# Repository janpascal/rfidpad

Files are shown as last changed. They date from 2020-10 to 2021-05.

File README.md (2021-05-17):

# rfidpad
Hardware, firmware, and Home Assistant integration for an ESP32 based device to enable and disable a Home Assistant alarm system

# Design goals
- low-cost (at most 50 euros per panel, comparable to the Zipato RFID Mini Keypad)
- arm and disarm Home Assistant alarm system using cheap RFID tags
- panel should not require any wiring
- panel should run on battery power for at least one year

And if possible also:
- Configure tags in Home Assistant UI
- Display list of recent arm and disarm actions in Home Assistant
- Associate name with each tag
- Enabled tags should not be stored in the panel, only in Home Assistant

# Hardware panel
- Based on low power ESP32 board from EZSBC with a LiPo battery (https://www.ezsbc.com/index.php/products/wifi01-cell10.html) and PN532 board from Elechouse (https://www.elechouse.com/elechouse/index.php?main_page=product_info&cPath=90_93&products_id=2276).
- The device will spend most of the time in deep sleep. The ESP32 should draw less than 20 μA in deep sleep. The PN532 chip itself has a deep sleep mode that should draw around 10 μA.
- Three pushbuttons to wake up the device and select the new alarm mode (disarm, arm home, arm away)
- After waking up the device, it will connect to WiFi and an MQTT server
- When an RFID tag is detected, its ID is sent over MQTT, together with the desired new alarm mode
- The device listens on MQTT for messages about the Home Assistant alarm mode.
- Three LEDs on the panel to display the current alarm mode. Also serves as feedback to the user that the mode has been successfully changed

## Hardware challenges:
- Power usage. The PN532 board has an LED that burns as long as the board is powered. That means the Vcc of the PN532 will need to be switched using e.g. a FET to prevent the board from using too much power during the deep sleep period. Also, the deep sleep mode of the PN532 chip isn't supported by the library supplied by Elechouse.
- Housing, including the pushbutton and status LEDs.

# Enclosure
The enclosure is designed with FreeCad. It contains of three parts which should be 3D printable.

# Firmware
Use the Arduino IDE to compile the firmware. Select the ESP32 dev board as the
target. Upload it to your RFIDPad

# Home Assistant custom component

## Prerequisities
You will need an MQTT server such as Mosquitto. Configure MQTT in your Home
Assistant installation. Give the homeassistant user read access to
`rfidpad/discovery/#`, to `rfidpad/+/battery` and to `rfidpad/+/action`.
Give it write access to `rfidpad/+/status`.

Add an `rfidpad` user and give it write access to 
`rfidpad/discovery/#`, to `rfidpad/+/battery` and to `rfidpad/+/action`.
Give it write access to `rfidpad/+/status`.

## Installation via HACS
- First install HACS in Home assistant. See https://hacs.xyz/ for instructions.
- Open the Community panel in Home Assistant
- Open the 'hamburger menu' and select 'Custom repositories'
- Enter https://github.com/janpascal/rfidpad where it says 'Add custom repository URL'. In the Category dropdown select 'Integration' and click 'Add' 
- Now press the big '+' on the bottom of the screen. Search for 'RFIDPad', select it and click on 'Install this repository in HACS'
- Configure the RFID custom component by filling in the base MQTT topic. The default (rfidpad) will do if you haven't changed the firmware.

## Configuration
The tags that can be used to arm/disarm your Home Assistant alarm need to be
configured in Home Assistant's `configuration.yaml` configuration file.
Add a snippet like:

```
rfidpad:
  tags:
    - tag: ABCD0145
      name: Mary
    - tag: 45AB12EC
      name: John
```

and restart Home Assistant

## Automations

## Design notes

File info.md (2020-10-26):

# Development version
Please do not install this integration yet. It is in heavy development and probably will ot work at all with  your device.

{% if prerelease %}
### NB!: This is a Beta version!
{% endif %}

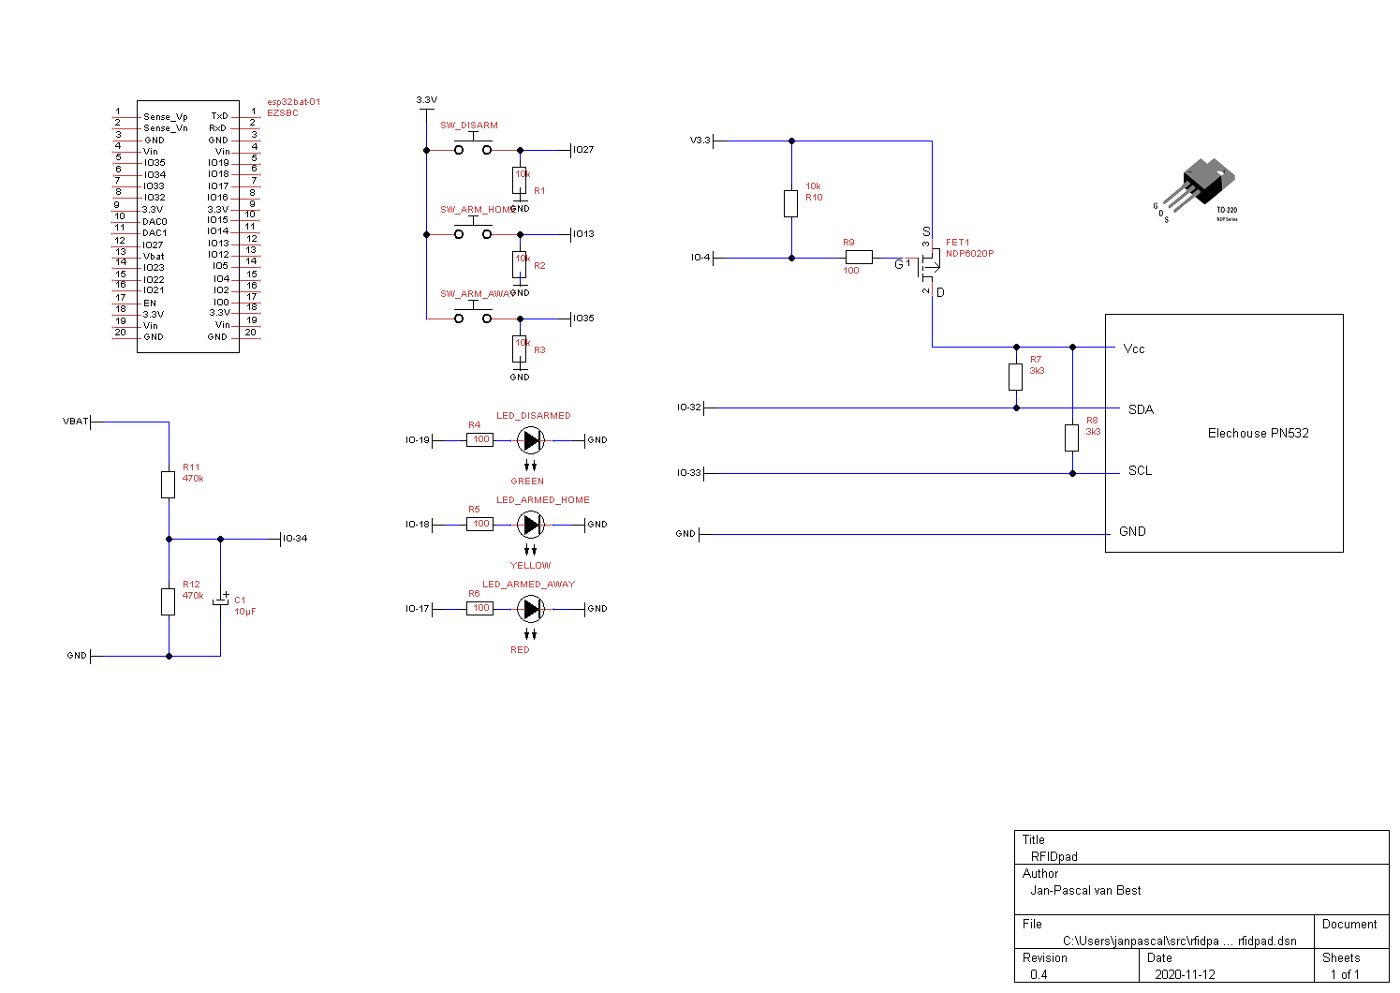
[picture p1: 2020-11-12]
schematic/rfidpad.png

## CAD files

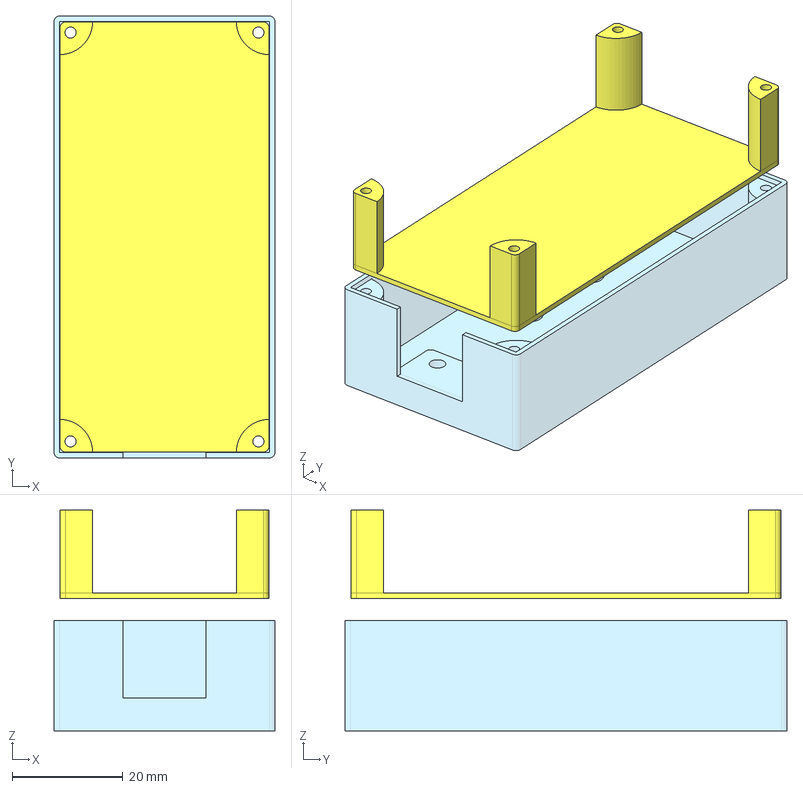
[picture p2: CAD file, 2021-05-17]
enclosure/rfidpad.FCStd
40.0 x 80.0 x 40.0 mm
Inlay

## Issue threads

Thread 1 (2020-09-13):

Panel uses too much power

janpascal, 2020-09-13:
At least, use a FET or something to cut the power to the PN532 board, since if anything the LED keeps burning when the rest of the panel is in deep sleep

janpascal, 2020-11-12:
Should be fixed now by using a FET to cut power to the PN532 board. With lots of help from the Arduino forum: https://forum.arduino.cc/?topic=705265

Closed 2020-11-12.

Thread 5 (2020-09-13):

Housing

janpascal, 2020-09-13:
Design a 3d printable housing for the rfidpad, including the pushbuttons, LEDs, esp32 board, pn532 board, maybe a reset pin, and a usb connector for charging the battery

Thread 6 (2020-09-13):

Battery level monitoring

janpascal, 2020-09-13:
also send out battery low warning, or the battery level itself, over MQTT
Shut down the device if the battery level gets too low to prevent damaging the battery

janpascal, 2020-11-12:
Battery monitor is implemented in schematic, firmware and home assistant integration.

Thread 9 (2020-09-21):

Allow access to config

janpascal, 2020-09-21:
Currently the device enters deep sleep in five seconds after boot. Make it possible to keep it awake long enough to change the device configuration

janpascal, 2020-11-12:
Fixed in firmware. Press multiple buttons at the same time to enter config mode

Closed 2020-11-12.

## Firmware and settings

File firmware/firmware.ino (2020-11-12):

/**
   firmware.ino -- part of rfidpad. 

   rfidpad is an ESP32 based device to enable and disable a Home 
   Assistant alarm system using RFID tags

   See https://github.com/janpascal/rfidpad for a hardware description
   and Home Assistant integration.

   Copyright (C) 2020 Jan-Pascal van Best <janpascal@vanbest.org>

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
    You should have received a copy of the GNU General Public License
    along with this program.  If not, see <https://www.gnu.org/licenses/>.
*/

#include <WiFiClientSecure.h>
#include <PubSubClient.h>
#include <IotWebConf.h>
#include <ArduinoJson.h>
#include <esp_system.h>

#define DEBUG
#include <Wire.h>
#include <PN532_debug.h>
#include <PN532_I2C.h>
#include <PN532.h>


#define DBG_OUTPUT_PORT Serial
#include <SPIFFS.h>

// I2C pins
#define PIN_SDA (32)
#define PIN_SCL (33)

// Pushbutton pins
#define PIN_DISARM_BUTTON 27
#define PIN_ARM_HOME_BUTTON 13
#define PIN_ARM_AWAY_BUTTON 35

// LED pins
#define PIN_DISARMED_LED 19
#define PIN_ARMED_HOME_LED 18
#define PIN_ARMED_AWAY_LED 17

// FET pin
#define PIN_ENABLE_PN532 4

// Battery voltage divider pin
#define PIN_BATTERY_DIVIDER 34


// -- When CONFIG_PIN is pulled to ground on startup, the Thing will use the initial
//      password to buld an AP. (E.g. in case of lost password)
//      -1 means no config pin
#define CONFIG_PIN -1

// -- Status indicator pin.
//      First it will light up (kept LOW), on Wifi connection it will blink,
//      when connected to the Wifi it will turn off (kept HIGH).
#define STATUS_PIN -1

// Stay awake for 10 seconds during normal operations
#define NORMAL_WAKE_TIME 10000

// Stay away for 10 minutes when multiple buttons were pressed during startup
#define CONFIG_WAKE_TIME 600000

// If no buttons are pushed, stay in deep sleep for this many microseconds
// When woken up, only send battery info and re-enter deep sleep
// Wake up every 24 hours
#define DEEP_SLEEP_TIMER_MICROSECONDS (1000000LL * 3600LL * 24)
// For debugging and power usage measurements: Wake up every minute
// #define DEEP_SLEEP_TIMER_MICROSECONDS (1000000LL * 60)

// Internal buffer size for MQTT library. Default of 256 is too small for discovery messages
#define MQTT_BUFFER_SIZE 512

enum requested_state_t {
  requested_state_unknown,
  requested_state_disarm_button,
  requested_state_arm_home_button,
  requested_state_arm_away_button,
  requested_state_config,
  requested_state_report
};

static const char *requested_state_actions[] = { "SCAN", "DISARM", "ARM_HOME", "ARM_AWAY", "SCAN", "SCAN" };

enum state_t {
  state_unknown,
  state_disarmed,
  state_disarmed_pending,
  state_armed_home,
  state_armed_home_pending,
  state_armed_away,
  state_armed_away_pending,
  state_config,                // CA certificate incomplete or double buttons pressed
  state_report                 // Just report battery level over MQTT and sleep again
};

// -- Initial name of the Thing. Used e.g. as SSID of the own Access Point.
const char thingName[] = "keypad";

// -- Initial password to connect to the Thing, when it creates an own Access Point.
const char wifiInitialApPassword[] = "pad323232";

const char action_topic_name[] = "action";
const char state_topic_name[] = "status";
const char battery_level_topic_name[] = "bat";

const char* caFilename = "/ca.crt";

const char* sw_version = "0.1";
const char* manufacturer = "janpascal@vanbest.org";
const char* model = "RFIDPAD v0.4";

// -- Configuration specific key. The value should be modified if config structure was changed.
#define CONFIG_VERSION "rfidpad_v1"

#define STRING_LEN 128
#define PORT_LEN 5
#define MAX_TOPIC_LEN 256

// -- Callback method declarations.
void configSaved();
boolean formValidator();

DNSServer dnsServer;
WiFiClientSecure net;
WebServer server(80);
PubSubClient mqttClient(net);
File fsUploadFile; //holds the current upload

TwoWire wire(0);
PN532_I2C pn532_i2c(wire);
PN532 pn532(pn532_i2c);

char mqttServerValue[STRING_LEN];
char mqttServerPortValue[PORT_LEN];
char mqttUserNameValue[STRING_LEN];
char mqttUserPasswordValue[STRING_LEN];
char mqttTopicPrefixValue[STRING_LEN];

IotWebConf iotWebConf(thingName, &dnsServer, &server, wifiInitialApPassword, CONFIG_VERSION);
IotWebConfParameter mqttServerParam = IotWebConfParameter("MQTT server", "mqttServer", mqttServerValue, STRING_LEN, "text", NULL, "bree.vanbest.eu");
IotWebConfParameter mqttServerPortParam = IotWebConfParameter("MQTT port", "mqttPort", mqttServerPortValue, PORT_LEN, "text", NULL, "1883"); // , "1883 for MQTT, 8883 for MQTTS");
IotWebConfParameter mqttUserNameParam = IotWebConfParameter("MQTT user", "mqttUser", mqttUserNameValue, STRING_LEN, "text", NULL, "keypad");
IotWebConfParameter mqttUserPasswordParam = IotWebConfParameter("MQTT password", "mqttPass", mqttUserPasswordValue, STRING_LEN, "password", NULL, "aeSheeciingeib6G");
IotWebConfParameter mqttTopicPrefixParam = IotWebConfParameter("MQTT prefix", "mqttPrefix", mqttTopicPrefixValue, STRING_LEN, "text", NULL, "rfidpad");
// -- We can add a legend to the separator
//IotWebConfSeparator separator2 = IotWebConfSeparator("Calibration factor");

boolean needMqttConnect = false;
unsigned long lastMqttConnectionAttempt = 0;
static int current_led = 0;
unsigned long mqttLastBatteryMessageTimestamp = 0;

// Overwritten at startup
char mqtt_status_channel[MAX_TOPIC_LEN] = "rfidpad/status";
char mqtt_action_channel[MAX_TOPIC_LEN] = "rfidpad/action";
char mqtt_discovery_channel[MAX_TOPIC_LEN] = "rfidpad/discovery/000000000000";
char mqtt_bat_channel[MAX_TOPIC_LEN] = "rfidpad/bat";
char device_id[] = "000000000000";
char device_name[STRING_LEN] = "<unknown>";

requested_state_t requested_state = requested_state_unknown;
state_t current_state = state_unknown;
int last_state_change = 0;
char mqtt_message_to_send[255] = "";

void setup()
{
  Serial.begin(115200);
  Serial.println();
  Serial.println("Starting up...");

  if (PIN_BATTERY_DIVIDER > 0) pinMode(PIN_BATTERY_DIVIDER, INPUT);

  if (PIN_DISARMED_LED > 0) pinMode(PIN_DISARMED_LED, OUTPUT);
  if (PIN_ARMED_HOME_LED > 0) pinMode(PIN_ARMED_HOME_LED, OUTPUT);
  if (PIN_ARMED_AWAY_LED > 0) pinMode(PIN_ARMED_AWAY_LED, OUTPUT);

  pinMode(PIN_DISARM_BUTTON, INPUT);
  pinMode(PIN_ARM_HOME_BUTTON, INPUT);
  pinMode(PIN_ARM_AWAY_BUTTON, INPUT);

  if (PIN_ENABLE_PN532 > 0) {
    pinMode(PIN_ENABLE_PN532, OUTPUT);
    digitalWrite(PIN_ENABLE_PN532, LOW);
  }

  requested_state = get_requested_state();
  if (requested_state == requested_state_config) {
    current_state = state_config;
  } else if (requested_state == requested_state_report) {
    current_state = state_report;
  } else {
    current_state = state_unknown;
  }


  // if (FORMAT_FILESYSTEM) SPIFFS.format();
  SPIFFS.begin();                           // Start the SPI Flash Files System

  iotWebConf.setStatusPin(STATUS_PIN);
  iotWebConf.setConfigPin(CONFIG_PIN);

  iotWebConf.addParameter(&mqttServerParam);
  iotWebConf.addParameter(&mqttServerPortParam);
  iotWebConf.addParameter(&mqttUserNameParam);
  iotWebConf.addParameter(&mqttUserPasswordParam);
  iotWebConf.addParameter(&mqttTopicPrefixParam);

  iotWebConf.setConfigSavedCallback(&configSaved);
  iotWebConf.setFormValidator(&formValidator);
  iotWebConf.setWifiConnectionCallback(&wifiConnected);
  //iotWebConf.getApTimeoutParameter()->visible = true;
  iotWebConf.skipApStartup(); // Do not always spend first 30 seconds in AP mode, only if config invalid

  // -- Initializing the configuration.
  bool validConfig = iotWebConf.init();
  if (!validConfig)
  {
    Serial.println("Invalid config, resetting Wifi info...");
    iotWebConf.resetWifiAuthInfo();
    strncpy(mqttServerValue, mqttServerParam.defaultValue, STRING_LEN);
    strncpy(mqttServerPortValue, mqttServerPortParam.defaultValue, PORT_LEN);
    strncpy(mqttUserNameValue, mqttUserNameParam.defaultValue, STRING_LEN);
    strncpy(mqttUserPasswordValue, mqttUserPasswordParam.defaultValue, STRING_LEN);
    strncpy(mqttTopicPrefixValue, mqttTopicPrefixParam.defaultValue, STRING_LEN);
  }

  Serial.println("Setting ca certificate to connection to MQTT server");
  if (!SPIFFS.exists(caFilename)) {
    Serial.printf("CA file %s does not exist!\n", caFilename);
  }
  File file = SPIFFS.open(caFilename, "r");

  if(!file) {
    Serial.printf("Error opening the CA file %s\n.", caFilename);
  } else {
    String ca_cert = file.readString();
    Serial.printf("CA Root certificate: %s\n", ca_cert.c_str());
    char *tmp;  
    tmp = (char *)malloc(sizeof(char) * (ca_cert.length()+1));
    strcpy(tmp, ca_cert.c_str());
      
    net.setCACert(tmp);
    file.close();
    // free(tmp);      
  }

  IotWebConfParameter* ap_passwd_param = iotWebConf.getApPasswordParameter();
  char* pw = ap_passwd_param->valueBuffer;
  Serial.print("Config password: ");
  Serial.println(pw);

  IotWebConfParameter* thing_name_param = iotWebConf.getThingNameParameter();
  strncpy(device_name, thing_name_param->valueBuffer, sizeof(device_name));
  device_name[sizeof(device_name)-1] = 0;
  Serial.printf("Device name: %s\n", device_name);

  Serial.printf("Fetching hardware id...\n");
  fetch_device_id();
  Serial.printf("Device ID: %s\n", device_id);
  
  Serial.println("Setting up MQTT topic names...");
  snprintf(mqtt_status_channel, MAX_TOPIC_LEN, "%s/%s/%s", mqttTopicPrefixValue, device_id, state_topic_name);
  snprintf(mqtt_action_channel, MAX_TOPIC_LEN, "%s/%s/%s", mqttTopicPrefixValue, device_id, action_topic_name);
  snprintf(mqtt_discovery_channel, MAX_TOPIC_LEN, "%s/discovery/%s", mqttTopicPrefixValue, device_id);
  snprintf(mqtt_bat_channel,    MAX_TOPIC_LEN, "%s/%s/%s", mqttTopicPrefixValue, device_id, battery_level_topic_name);
  Serial.printf("* status topic: %s\n", mqtt_status_channel);
  Serial.printf("* action topic: %s\n", mqtt_action_channel);
  Serial.printf("* config topic: %s\n", mqtt_discovery_channel);
  Serial.printf("* battery level topic: %s\n", mqtt_bat_channel);

  // -- Set up required URL handlers on the web server.
  server.on("/", handleRoot);
  server.on("/config", [] { iotWebConf.handleConfig(); });
  server.on("/upload_cert", HTTP_POST,                       // if the client posts to the upload page
    [](){ server.send(200); },                          // Send status 200 (OK) to tell the client we are ready to receive
    handleCertUpload                                    // Receive and save the file
  );
  server.onNotFound([]() {
    iotWebConf.handleNotFound();
  });


  mqttClient.setCallback(mqttMessageReceived);
  if (!mqttClient.setBufferSize(MQTT_BUFFER_SIZE)) {
    Serial.printf("Failed to set mqtt buffer size to %d\n", MQTT_BUFFER_SIZE);
  }

  Serial.println("Setting up i2c...");
  if (!wire.begin(PIN_SDA, PIN_SCL)) {
    Serial.println("Failed to initialise i2c");
    enter_deep_sleep();
  }

  Serial.println("Beginning pn532_i2c...");
  pn532_i2c.begin();

  Serial.println("Waking up pn532_i2c...");
  pn532_i2c.wakeup();

  Serial.println("Beginning PN532...");
  pn532.begin();

  Serial.println("Attempting to get pn532 firmware version...");
  uint32_t versiondata = pn532.getFirmwareVersion();
  if (! versiondata) {
    Serial.println("Didn't find PN53x board, bailing out!");
    Serial.println("Nope, ignoring to see what happens...");
    // enter_deep_sleep();
  }

  // Got ok data, print it out!
  Serial.print("Found chip PN5"); Serial.println((versiondata >> 24) & 0xFF, HEX);
  Serial.print("Firmware ver. "); Serial.print((versiondata >> 16) & 0xFF, DEC);
  Serial.print('.'); Serial.println((versiondata >> 8) & 0xFF, DEC);

  // Set the max number of retry attempts to read from a card
  // This prevents us from waiting forever for a card, which is
  // the default behaviour of the PN532.
  if (!pn532.setPassiveActivationRetries(0x01)) {
    Serial.println("Failed to set Passive activation retry count, ignoring!");
  }

  // configure board to read RFID tags
  if (!pn532.SAMConfig()) {
    Serial.println("SAMConfig failed, ignoring!");
  }

  wire.flush();

  Serial.println("Ready.");
}

void fetch_device_id() {
  uint8_t baseMac[6];
  // Get MAC address for WiFi station
  esp_read_mac(baseMac, ESP_MAC_WIFI_STA);
  snprintf(device_id, sizeof(device_id), "%02X%02X%02X%02X%02X%02X", baseMac[0], baseMac[1], baseMac[2], baseMac[3], baseMac[4], baseMac[5]);
}

// call back
void wifiConnected()
{
  Serial.println("Wifi is connected, signalling to start MQTT...");
  needMqttConnect = true;
}
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
void loop()
{
  // -- doLoop should be called as frequently as possible.
  iotWebConf.doLoop();
  mqttClient.loop();

  // Serial.println("Checking to (re)connect MQTT...");
  reconnect_mqtt();
  
  // Serial.println("Pinging MQTT...");
  publish_battery_level();

  //Serial.println("Handling nfc...");
  handle_nfc();

  //Serial.println("Checking for pressed button...");
  update_requested_state_from_buttons();
  
  if (current_state != state_report) {
      // Only if not in report mode
      //Serial.println("Updating state LEDs...");
      update_state_leds(current_state);
  }

  //Serial.println("Checking if we need to send an MQTT message...");
  if (mqtt_message_to_send[0] != 0 && mqttClient.connected())
  {    
    Serial.printf("Publishing %s to %s\n", mqtt_message_to_send, mqtt_action_channel); 
    mqttClient.publish(mqtt_action_channel, mqtt_message_to_send);
    mqtt_message_to_send[0] = 0;
  }

  // If we're in report mode and mqtt has connected, send battery level and go to sleep
  if (current_state == state_report && mqttClient.connected()) {
      Serial.println("We're in report state and MQTT has just connected");
      publish_battery_level();
      enter_deep_sleep();
  }
  
  //Serial.println("Checking if we need to shut down...");
  if (current_state != state_config && millis() - last_state_change > NORMAL_WAKE_TIME) {
    int awake_time = millis() - last_state_change;
    Serial.printf("Been awake without action for more than %d ms, going to deep sleep...\n", millis() - last_state_change);
    // mqttClient.publish(mqtt_action_channel, "Going to sleep");
    enter_deep_sleep();
  }

  //Serial.println("Checking if we need to shut down in config mode...");
  if (current_state == state_config && millis() - last_state_change > CONFIG_WAKE_TIME) {
    Serial.printf("In Config mode, but awake without action for more than %d ms, going to deep sleep...\n", millis() - last_state_change);
    enter_deep_sleep();
  }

  //Serial.println("Waiting 50ms...");
  delay(50);
}

void enter_deep_sleep()
{
  Serial.println("Preparing for deep sleep:");
  
  Serial.println("* Shutting down Wifi");
  WiFi.disconnect(true);
  WiFi.mode(WIFI_OFF);

  Serial.println("* Turning off I2C");
  wire.~TwoWire();
  pinMode(PIN_SDA, INPUT);
  pinMode(PIN_SCL, INPUT);

  Serial.println("* Turning off PN532");
  // No use, led stays on anyways. Kill the power (using a FET) instead!
  // pn532.shutDown(0x80, false); // 0x80: wake up on I2C

  if (PIN_ENABLE_PN532 > 0) {
    digitalWrite(PIN_ENABLE_PN532, HIGH);
    pinMode(PIN_ENABLE_PN532, INPUT);
  }

  Serial.println("Entering deep sleep until woken by button...");
  uint64_t mask = ( 1ULL << PIN_DISARM_BUTTON ) | ( 1ULL << PIN_ARM_HOME_BUTTON ) | ( 1ULL << PIN_ARM_AWAY_BUTTON );
  //uint64_t mask = ( 1ULL << PIN_DISARM_BUTTON );
  // ( 0x8000000 + 0x400000000 + 0x800000000 )
  char msg[80];
  snprintf(msg, 80, "Deep sleep mask: %016llx", mask);
  Serial.println(msg);
  esp_sleep_enable_ext1_wakeup(mask, ESP_EXT1_WAKEUP_ANY_HIGH);
  esp_sleep_enable_timer_wakeup(DEEP_SLEEP_TIMER_MICROSECONDS);
  esp_deep_sleep_start();
}

int bytes_to_hex(char* s, int maxlen, byte* bytes, int count)
{
  if (maxlen < 2*count + 1) {
    return -1;
  }
  for (int i = 0; i < count; i++)
  {
    int hi = bytes[i] >> 4;
    int lo = bytes[i] && 0x0f;
    s[2*i] = (hi < 10 ? hi + '0' : hi + 'A' - 10);
    s[2*i + 1] = (lo < 10 ? lo + '0' : lo + 'A' - 10);
  }
  s[2*count] = 0;
  return 2*count;
}

void handle_nfc()
{
  // Serial.println("\nPlease scan an NFC tag\n");
  boolean success;
  uint8_t uid[] = { 0, 0, 0, 0, 0, 0, 0 };  // Buffer to store the returned UID
  uint8_t uidLength;                        // Length of the UID (4 or 7 bytes depending on ISO14443A card type)
  char uid_string[2*7+1];

  // Wait for an ISO14443A type cards (Mifare, etc.).  When one is found
  // 'uid' will be populated with the UID, and uidLength will indicate
  // if the uid is 4 bytes (Mifare Classic) or 7 bytes (Mifare Ultralight)
  success = pn532.readPassiveTargetID(PN532_MIFARE_ISO14443A, &uid[0], &uidLength);

  if (success) {
    Serial.println("Found a card!");
    if (bytes_to_hex(uid_string, sizeof(uid_string), uid, uidLength) < 0) {
      Serial.println("Failed to convert UID to hex string");
      return;
    }

    Serial.printf("UID Value: %s\n", uid_string);

    StaticJsonDocument<200> doc;
    doc["button"] = requested_state_actions[requested_state];
    doc["tag"] = uid_string;
    String msg;
    serializeJson(doc, msg);

    strncpy(mqtt_message_to_send, msg.c_str(), sizeof(mqtt_message_to_send));
    Serial.printf("Queueing message to send: '%s'\n", mqtt_message_to_send);

    if (requested_state == requested_state_disarm_button) set_state(state_disarmed_pending);
    if (requested_state == requested_state_arm_home_button) set_state(state_armed_home_pending);
    if (requested_state == requested_state_arm_away_button) set_state(state_armed_away_pending);
  }
  wire.flush();
}

boolean connectMqtt() {
  unsigned long now = millis();
  if (1000 > now - lastMqttConnectionAttempt)
  {
    // Do not repeat within 1 sec.
    return false;
  }
  Serial.println("Connecting to MQTT server...");
  if (!connectMqttOptions()) {
    Serial.println("Failed to connect to MQTT server!");
    lastMqttConnectionAttempt = now;
    return false;
  }
  Serial.println("MQTT Connected!");

  Serial.printf("Subscribing to mqtt %s\n", mqtt_status_channel);
  mqttClient.subscribe(mqtt_status_channel);

  Serial.printf("Sending discovery information to %s\n", mqtt_discovery_channel);
  StaticJsonDocument<200> doc;
  doc["name"] = device_name;
  doc["id"] = device_id;
  doc["base_topic"] = String(mqttTopicPrefixValue) + "/" + String(device_id);
  doc["status_topic"] = state_topic_name;
  doc["action_topic"] = action_topic_name;
  doc["battery_topic"] = battery_level_topic_name;
  doc["model"] = model;
  doc["manufacturer"] = manufacturer;
  doc["sw_version"] = sw_version;

  String msg;
  size_t msg_size = serializeJson(doc, msg);
  
  Serial.printf("Discovery info: %s\n", msg.c_str());
  if (! mqttClient.publish(mqtt_discovery_channel, msg.c_str(), /*retain*/ true)) {
    Serial.println("Failed to publish discovery message");
  }
  return true;
}

/**
   Handle web requests to "/" path.
*/
void handleRoot()
{
  Serial.println("Entering handleRoot()");
  // -- Let IotWebConf test and handle captive portal requests.
  if (iotWebConf.handleCaptivePortal())
  {
    // -- Captive portal request were already served.
    Serial.println("Connection had been handled by captive portal");
    return;
  }
  float battery_percentage = get_battery_percentage();
  String s = "<!DOCTYPE html><html lang=\"en\"><head><meta name=\"viewport\" content=\"width=device-width, initial-scale=1, user-scalable=no\"/>";
  s += "<title>IotWebConf based keypad</title></head><body><p>Hello world!</p>";
  s += "<p>Go to <a href='config'>configure page</a> to change values.</p>";
  s += "<form action=\"upload_cert\" method=\"post\" enctype=\"multipart/form-data\">";
  s += "  <input type=\"file\" name=\"name\">";
  s += "  <input class=\"button\" type=\"submit\" value=\"Upload\">";
  s += "</form>";
  s += "</p>Battery level: ";
  s += battery_percentage;
  s += "%</p>";
  
  s += "</body></html>\n";

  server.send(200, "text/html", s);
}

void handleCertUpload(){ // upload the MQTT CA Certificate to the SPIFFS
  HTTPUpload& upload = server.upload();
  if(upload.status == UPLOAD_FILE_START){
    String filename = caFilename;
    Serial.print("handleCertUpload Name: "); Serial.println(filename);
    fsUploadFile = SPIFFS.open(filename, "w");            // Open the file for writing in SPIFFS (create if it doesn't exist)
    filename = String();
  } else if(upload.status == UPLOAD_FILE_WRITE){
    if(fsUploadFile)
      fsUploadFile.write(upload.buf, upload.currentSize); // Write the received bytes to the file
  } else if(upload.status == UPLOAD_FILE_END){
    if(fsUploadFile) {                                    // If the file was successfully created
      fsUploadFile.close();                               // Close the file again
      Serial.print("handleCertUpload Size: "); Serial.println(upload.totalSize);
      server.sendHeader("Location","/");      // Redirect the client to the index
      server.send(303);
    } else {
      server.send(500, "text/plain", "500: couldn't create ca certificate file");
    }
  }
}

void configSaved()
{
  Serial.println("Configuration was updated.");
}
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

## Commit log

2020-09-11 Initial esp32 firmware
2020-09-12 Added initial schematic. Works, but not battery friendly
    [rfidpad.dsn]
2020-09-13 Added PNG of initial schematic
2020-09-13 Fix copyright statement in firmare source file
    [firmware.ino]
2020-09-16 Updated schematic to use FET to switch PN532. Issue #1
    [rfidpad.dsn]
2020-09-22 Allow upload of mqtt ca certificate. Introduce config mode, keeps device awake for 10 minutes, when two or more buttons are used to wake the device
2020-09-22 Schematic: add FET to power down PN532 entirely
    [rfidpad.dsn]
2020-10-07 Schematic minor refinements
    [rfidpad.dsn]
2020-10-14 Update schematic: add battery monitor circuit and change some IO ports
    [rfidpad.dsn]
2020-10-14 Firmware: report battery level; deep sleep optimisations; turn off Wifi before sleeping to prevent reconnect problems; do not use pin 2 since it seems to hinder programming via usb
    [firmware.ino]
2020-11-09 Detect RFIDPad devices using mqtt and show battery level
2020-11-11 Add service to send status to devices
2020-11-12 firmware: fix base topic in discovery info
    [firmware.ino]
2020-11-12 Fix button read at boot; allow to change into config state after boot by pressing multiple buttons
    [firmware.ino]
2020-11-12 Custom component: send updated status to all boards if tag accepted
2020-11-12 Firmware: wake up every 24 hours to report battery level. Closes #10
2020-11-12 Schematic: give all parts unique name :)
    [rfidpad.dsn]
2020-11-12 Schematic v0.4. Use 10u capacitor for stabilising Vbat measurement instead of 10n
    [rfidpad.dsn]
2020-11-12 Retain state message so board can directly show correct state
2021-05-17 Added partly done enclosure (FreeCad design)
    [rfidpad.FCStd]

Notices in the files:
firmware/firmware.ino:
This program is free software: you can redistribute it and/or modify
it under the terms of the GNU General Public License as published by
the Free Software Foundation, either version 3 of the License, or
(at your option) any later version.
